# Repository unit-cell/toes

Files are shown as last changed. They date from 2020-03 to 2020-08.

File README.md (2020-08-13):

# toes
A device that sends USB and DIN MIDI messages using four footswitches, a sustain pedal and an expression pedal as the interface. This project is a very easy DIY build that consists of very few through-hole components, recommended for beginners!

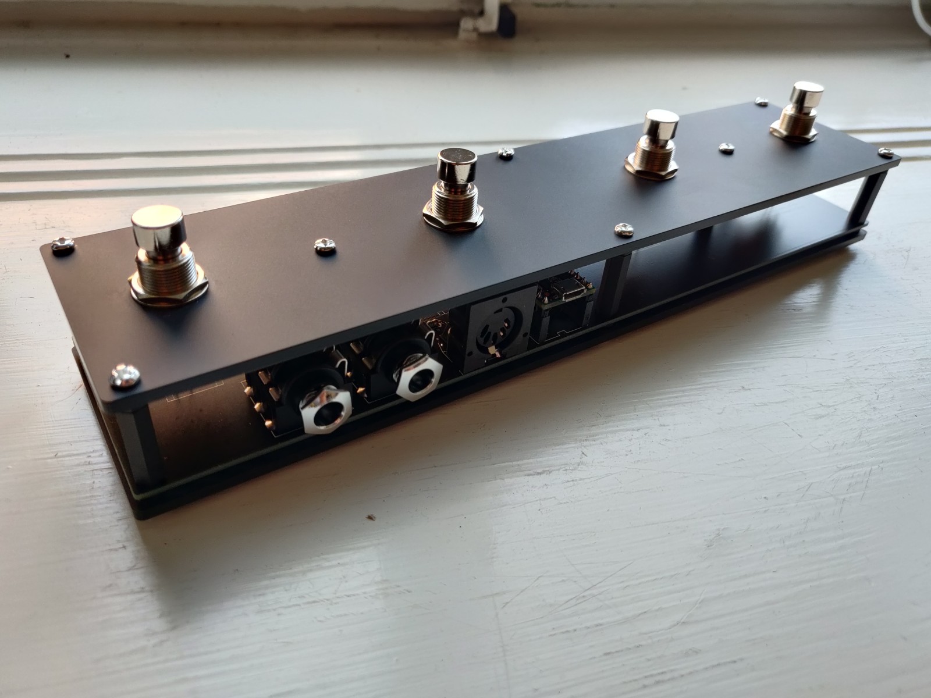
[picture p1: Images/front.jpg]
front


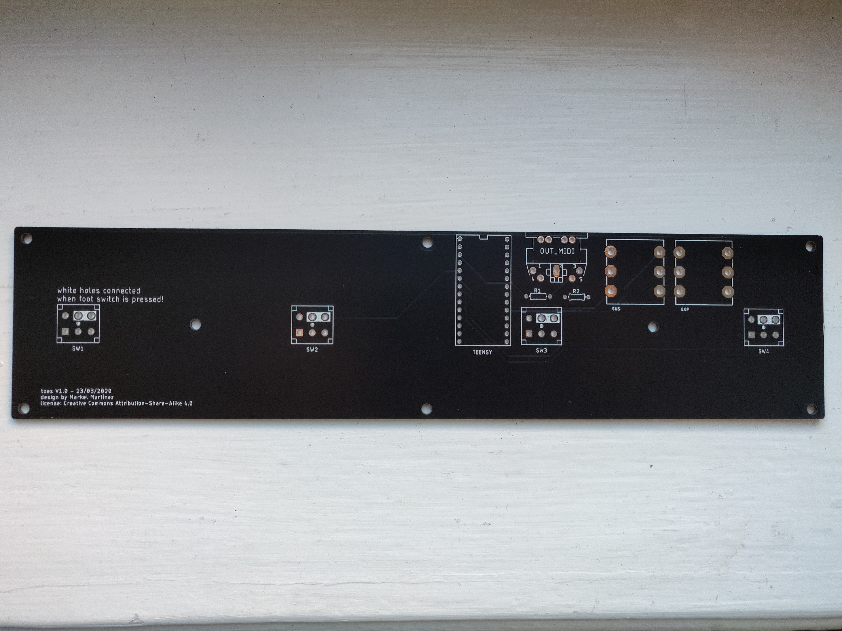
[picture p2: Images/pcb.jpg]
pcb


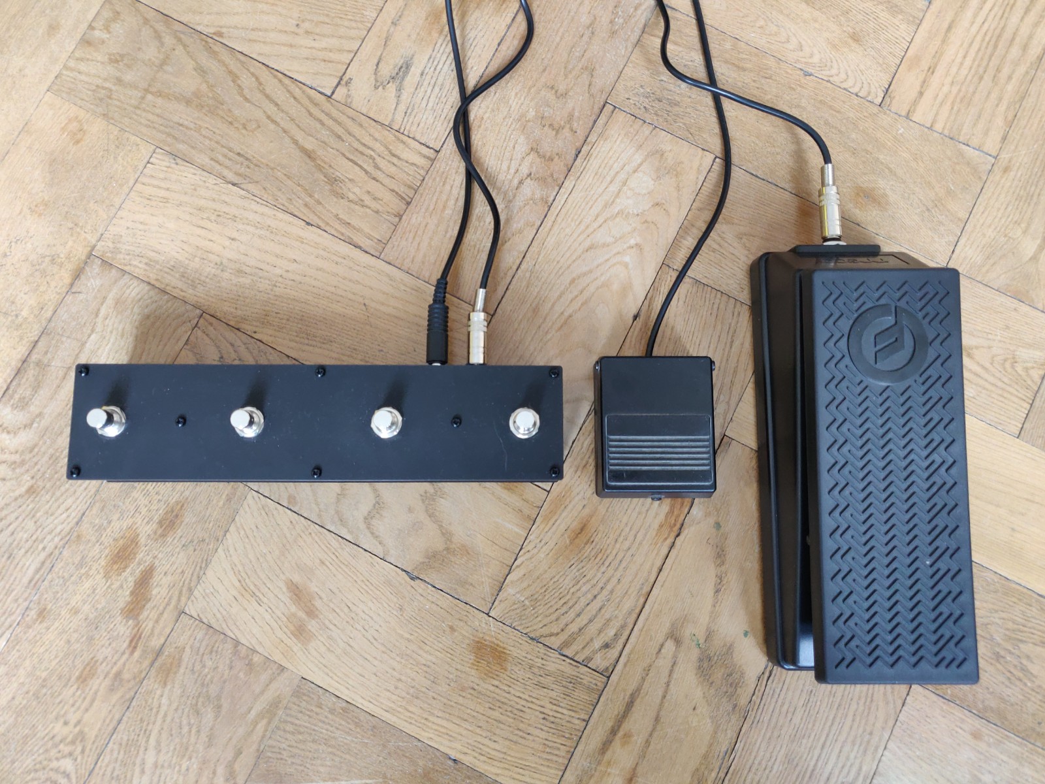
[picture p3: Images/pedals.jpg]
pedals


## Software
Requirements: Bounce2 library, MIDI library (found in Arduino IDE library manager).

To set custom MIDI messages, change settings in config.h file and then compile.

## Foot switches 
They send a note on MIDI message when pressed, and a note off message when released.

## Sustain and expression pedals
The sustain pedal works the same as the foot switches. It is assumed that the sustain pedal will short the tip and sleeve of the jack while it is not pressed, and interrupt the connection when it is pressed. The code could be modified for the opposite situation.

The expression pedal sends a MIDI CC message. This design carries 5V on the tip, the wiper on the ring, and ground on the sleeve of the TRS jack.

## USB and DIN midi
The USB port on the teensy powers the unit and sends USB midi messages, and there is also a DIN MIDI out socket.

## Build guide
First solder R1, R2, the teensy pin sockets, MIDI DIN socket, and the stereo jack sockets for the pedals. All of them go on the top of the board, as shown in the picture below. **Do not solder the foot switches yet, if you are are building toes with a MIDI DIN socket**.*

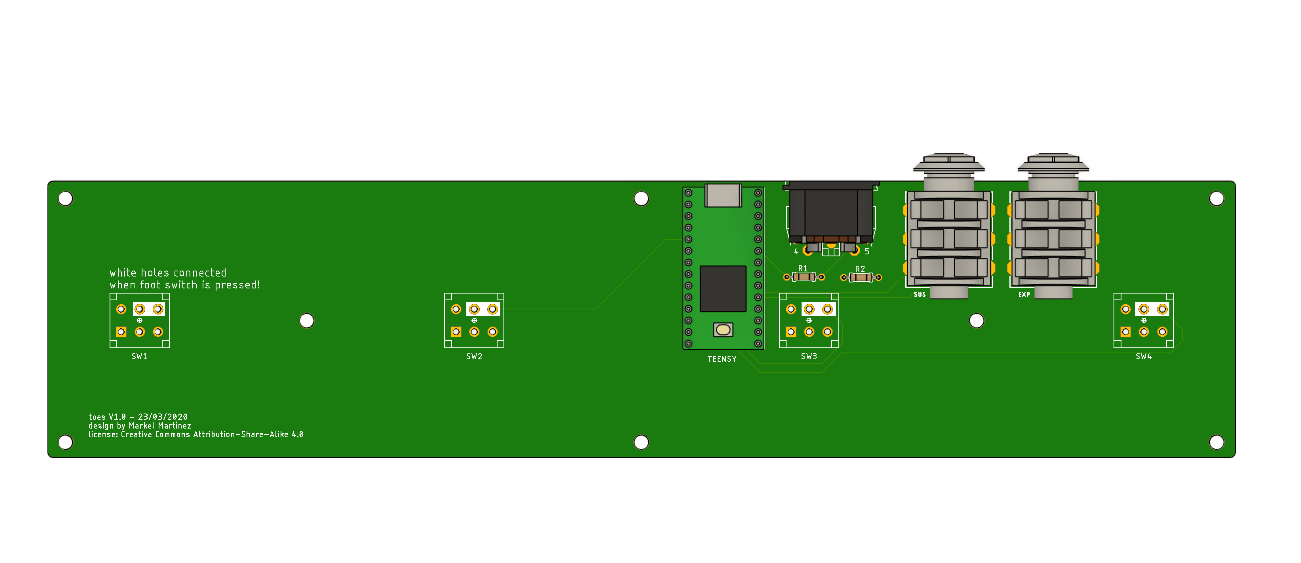
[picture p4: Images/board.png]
toes board


Then screw the foot switches to the top panel. Solder short cables or resistor legs to the foot switch legs that will be connected to the PCB. These are the legs that *become connected when the foot switch is pressed*. Mount the PCB to the top panel with the 22 mm spacers (I used a 20 mm spacer + a nut), and solder the wire/legs to the pads highlighted by the white mark on the silkscreen.

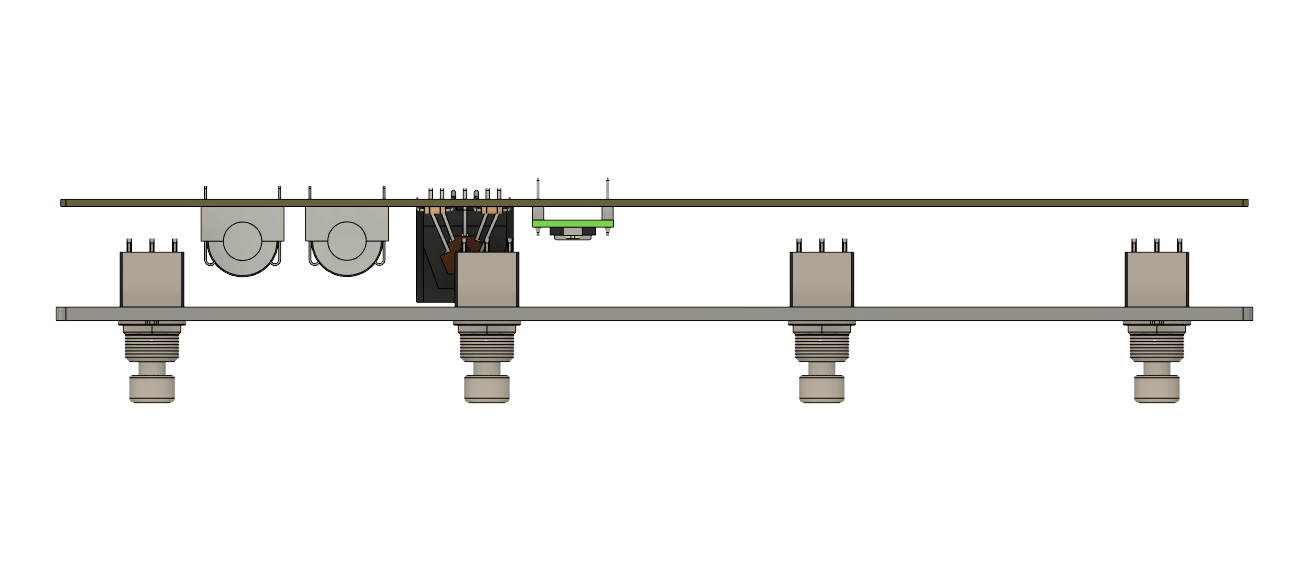
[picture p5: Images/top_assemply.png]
top assembly


You can trim the long legs on the bottom of the board if you are using nuts as spacers for the bottom panel. Assemble these and you are done!

Note about foot switches: it is possible to use any momentary foot switch with enough clearance to fit between the top panel and the board. Just make sure to wire it to the holes marked with a white rectangle, so that these become connected when pressing the switch.

*If you want a lower profile and don't need a MIDI DIN socket, you can get the footswitches listed in the BOM as FS5700SPMT2B2M2QE. These have solder pins instead of solder lugs and can be soldered directly on to the board.

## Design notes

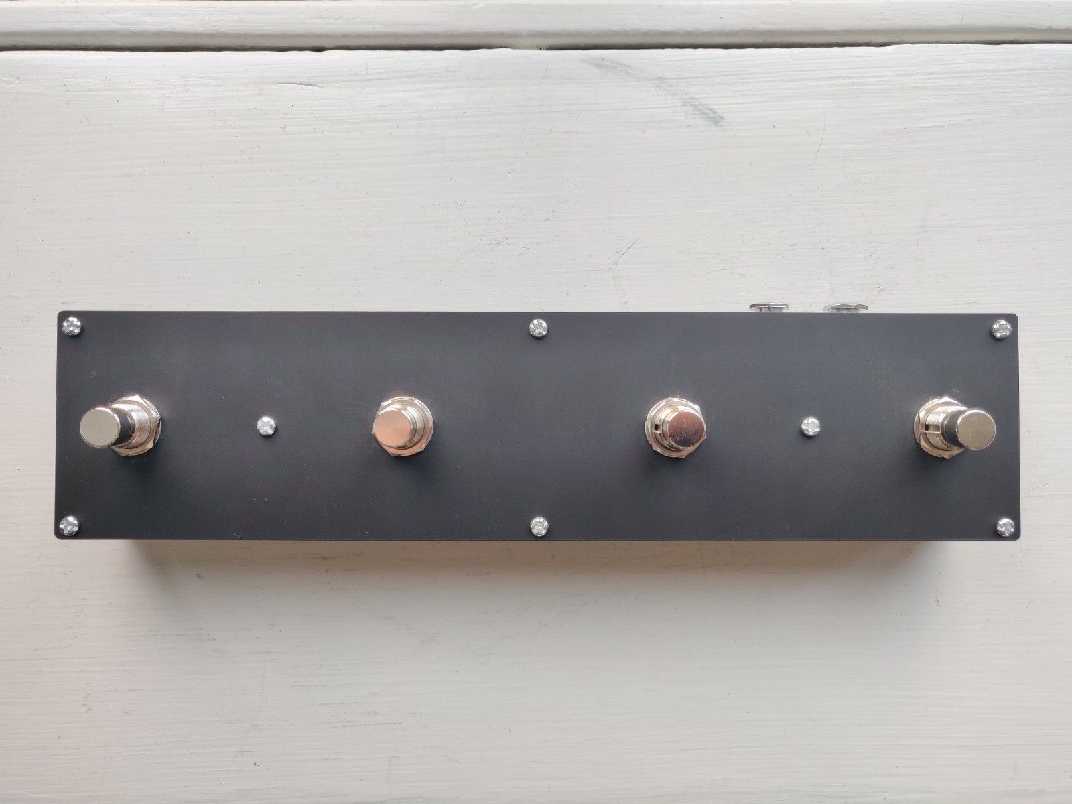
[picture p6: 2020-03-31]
Images/top.jpg

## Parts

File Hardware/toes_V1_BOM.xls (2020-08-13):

Toes BOM
Part | Quantity | Value | Mouser ref | Comments
R1, R2 | 2 | 47 ohm | 660-MFS1/4DCT52R47R0 | -
SW1-4 | 4 | - | 612-FS57SPMT2B2M1QE* | Use FS57SPMT2B2M2QE if you don't need DIN midi and will solder these to the board directly! These have solder pins instead of solder lugs.
MIDI socket | 1 | - | 502-57PC5F | Any 5 pin PCB mounted female socket will do.
SUS, EXP | 2 | - | 550-22302 | Stereo ¼ inch jacks.
Teensy pin sockets | 2 | - | 200-SLW11401TS | 14 position female pin strips.
Teensy 3.2 | 1 | - | 485-2756 | Might be cheaper from other sources.
Hardware
Part | Quantity | Comments
M3 screws long | 8 | Bottom side.
M3 screws short | 8 | Top side.
M3 FF spacers 22 mm | 8 | You can stack 2 spacers to a height of roughly 22 mm.
M3 nuts 2 mm | 8 | These are for the bottom side of the PCB.
Rubber feet | 4 | -
* Make sure that the legs you solder to the holes under the white rectangle mark are connected only when the switch is pressed! Test continuity with a multimeter if you are unsure.

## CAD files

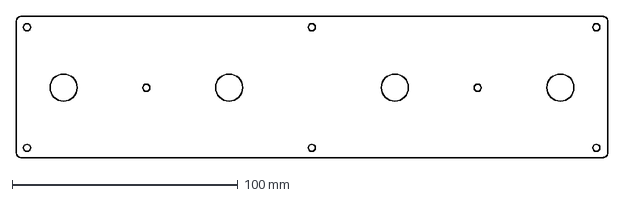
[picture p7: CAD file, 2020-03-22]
Hardware/toes_panel_top.dxf
262.0 x 62.5 mm

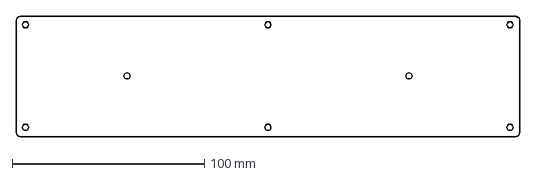
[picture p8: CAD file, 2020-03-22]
Hardware/toes_panel_bottom.dxf
262.0 x 62.5 mm

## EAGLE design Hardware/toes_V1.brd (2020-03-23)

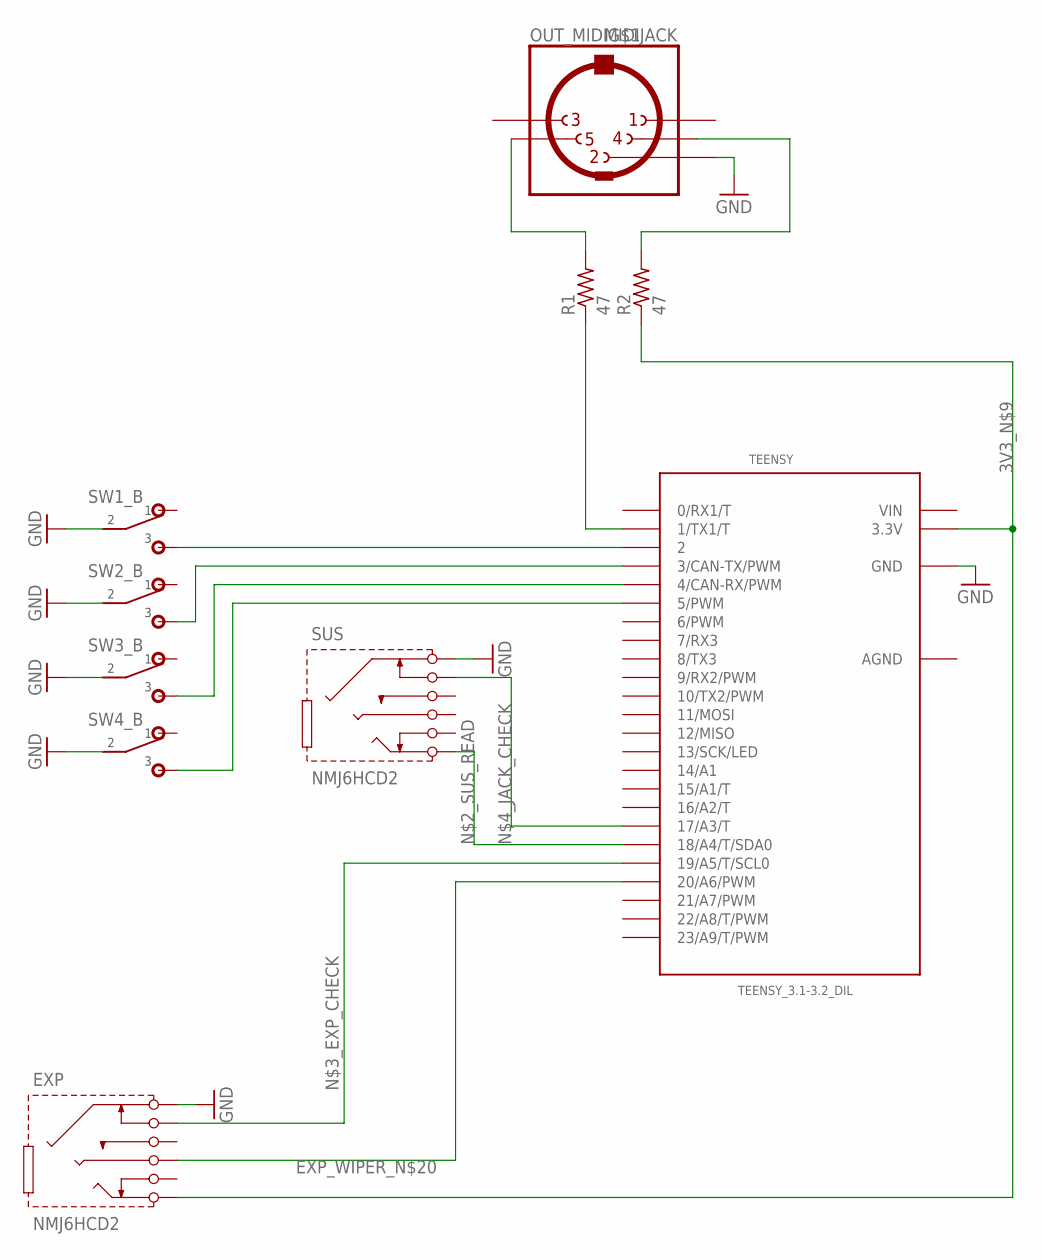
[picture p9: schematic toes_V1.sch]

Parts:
EXP: NMJ6HCD2
OUT_MIDI: MIDIJACK; CP-2350
R1, R2: 47; 0204/7
SUS: NMJ6HCD2
SW1, SW2, SW3, SW4: DPDTDPDT_MOM; SF12011F-0202-20R-M-011
TEENSY: TEENSY_3.1-3.2_DIL; TEENSY_3.0-3.2&LC_DIL

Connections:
3V3_N$9: EXP.T (TIP), R2.1, TEENSY.3.3V
AGND: TEENSY.AGND
EXP_WIPER_N$20: EXP.R (RING), TEENSY.20/A6 (20/A6/PWM)
GND: EXP.S (SLEEVE), OUT_MIDI.2, SUS.S (SLEEVE), SW1.P$5 (2), SW2.P$5 (2), SW3.P$5 (2), SW4.P$5 (2), TEENSY.GND
MIDI_OUT_N$8: R1.1, TEENSY.1 (1/TX1/T)
unnamed: OUT_MIDI.4, R2.2
unnamed: SUS.T (TIP), TEENSY.18/A4 (18/A4/T/SDA0)
unnamed: OUT_MIDI.5, R1.2
unnamed: EXP.SN (SLEEVE-S), TEENSY.19/A5 (19/A5/T/SCL0)
unnamed: SUS.SN (SLEEVE-S), TEENSY.17/A3 (17/A3/T)
SW1_N$14: SW1.P$6 (3), TEENSY.2
SW2_N$15: SW2.P$6 (3), TEENSY.3 (3/CAN-TX/PWM)
SW3_N$16: SW3.P$6 (3), TEENSY.4 (4/CAN-RX/PWM)
SW4_N$17: SW4.P$6 (3), TEENSY.5 (5/PWM)
VIN: TEENSY.VIN

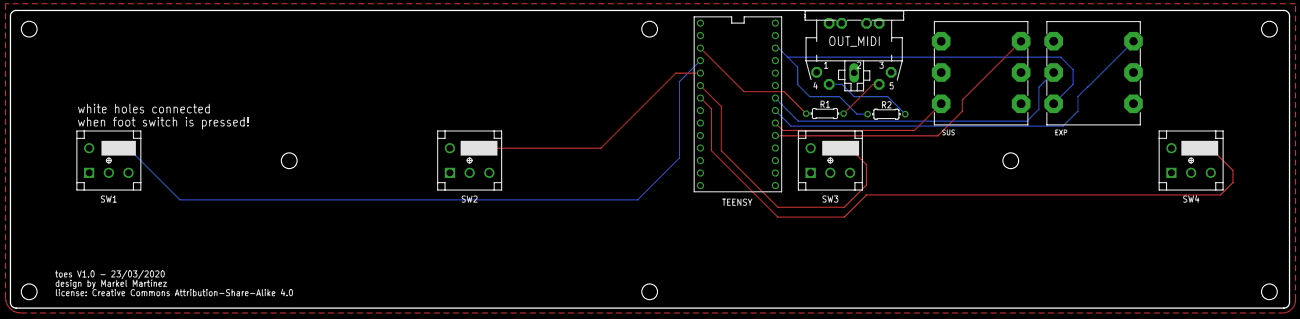
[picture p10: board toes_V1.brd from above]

Board: 2 copper layers, 260.0 x 60.5 mm, 10 parts (0 on the bottom side), 13 nets.

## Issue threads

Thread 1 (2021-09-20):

Where can we find the PCB?

julientaq, 2021-09-20:
Hi there
amazing project!
Do you have any plan to make those pcb available?

Thanks!

unit-cell, 2021-09-21:
Hey Julien, thanks for the kind words! The PCB files are on the github repo
if that's what you meant. I also have some PCBs left from my first order, I
have been sending them out for 80 SEK + shipping if you're interested.

Best,
Markel

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

julientaq, 2021-09-21:
That’s exactly what i had in mind :)

i’ll be happy to get a couple of pcb. i’m in france, so i don’t know how much the shipping would be. (but i’m all up for that)

unit-cell, 2021-09-21:
Great! Just checked and it seems the shipping would be 130 SEK. Let me know
if it sounds reasonable, and if you give me your address I can post them
asap!

Cheers,
Markel

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

julientaq, 2021-09-22:
We’re good!
How can i send you my address and the money?
I don’t really trust github to be the best place for that :)

unit-cell, 2021-09-22:
Right, did't even notice this was a github issue! I was following on my
email. You can email me your address at markelmc92 [at] gmail.com, we can
continue communicating there!

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

Closed 2021-09-22.

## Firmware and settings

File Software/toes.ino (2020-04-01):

#include <Bounce2.h>
#include <MIDI.h>
#include "config.h"

// MIDI 
MIDI_CREATE_INSTANCE(HardwareSerial, Serial1, MIDI);

// expression pedal
byte jack_check_exp = LOW;      // HIGH when exp. pedal present
byte jack_check_sustain = LOW;  // HIGH when sus pedal present
int expression = 0;             // exp. pedal reading on pin 20 (A6)
int expression_last = 0;        // exp. pedal reading from previous loop
int expression_threshold = 10;  // threshold for detection of movement
int cc_mapped = 0;              // reading mapped to 0-127              

// debouncing
Bounce sw1 = Bounce(2, 5); // debounce pin 2, 5ms debounce time
Bounce sw2 = Bounce(3, 5); // debounce pin 3, 5ms debounce time
Bounce sw3 = Bounce(4, 5); // debounce pin 4, 5ms debounce time
Bounce sw4 = Bounce(5, 5); // debounce pin 5, 5ms debounce time

Bounce sus_pedal = Bounce(18, 10); // debounce pin 18, 10 ms debounce time
Bounce jack_check_sus = Bounce(17, 5); // debounce pin 17, 5 ms debounce time

void setup() {
  MIDI.begin();
  // switches
  pinMode(2, INPUT_PULLUP);  // SW1
  pinMode(3, INPUT_PULLUP);  // SW2
  pinMode(4, INPUT_PULLUP);  // SW3
  pinMode(5, INPUT_PULLUP);  // SW4
   
  // expression pedal
  pinMode(19, INPUT_PULLUP); // jack_check_exp, LOW when no jack
  pinMode(A6, INPUT); // read voltage on wiper pin

  // sustain pedal
  pinMode(17, INPUT_PULLUP); // jack_check_sus, LOW when no jack
  pinMode(18, INPUT_PULLUP); // LOW when pressed
}

void loop() {
  // switch reading
  sw1.update();
  sw2.update();
  sw3.update();
  sw4.update();

  // switch MIDI messages
  if (sw1.fallingEdge()) {
    usbMIDI.sendNoteOn(note1, 99, midi_out_channel);  
    MIDI.sendNoteOn(note1, 99, midi_out_channel);
  }
  if (sw1.risingEdge()) {
    usbMIDI.sendNoteOff(note1, 0, midi_out_channel);
    MIDI.sendNoteOff(note1, 0, midi_out_channel); 
  }
  if (sw2.fallingEdge()) {
    usbMIDI.sendNoteOn(note2, 99, midi_out_channel);  
    MIDI.sendNoteOn(note2, 99, midi_out_channel);
  }
  if (sw2.risingEdge()) {
    usbMIDI.sendNoteOff(note2, 0, midi_out_channel);
    MIDI.sendNoteOff(note2, 0, midi_out_channel); 
  }
  if (sw3.fallingEdge()) {
    usbMIDI.sendNoteOn(note3, 99, midi_out_channel);  
    MIDI.sendNoteOn(note3, 99, midi_out_channel);
  }
  if (sw3.risingEdge()) {
    usbMIDI.sendNoteOff(note3, 0, midi_out_channel);
    MIDI.sendNoteOff(note3, 0, midi_out_channel); 
  }
  if (sw4.fallingEdge()) {
    usbMIDI.sendNoteOn(note4, 99, midi_out_channel);  
    MIDI.sendNoteOn(note4, 99, midi_out_channel);
  }
  if (sw4.risingEdge()) {
    usbMIDI.sendNoteOff(note4, 0, midi_out_channel);
    MIDI.sendNoteOff(note4, 0, midi_out_channel); 
  }

  // SUSTAIN PEDAL: if pin 17 NOT LOW, check if pin 18 is LOW and if so send note.
  jack_check_sus.update();
  sus_pedal.update();
  jack_check_sustain = digitalRead(17);

  // first IF is for sending note_off when unplugging jack.
  if (jack_check_sus.fallingEdge()){
    usbMIDI.sendNoteOff(note_sus, 0, midi_out_channel);
    MIDI.sendNoteOff(note_sus, 0, midi_out_channel);     
  }
  // these IF statements might have to be reversed for a different pedal
  if (jack_check_sustain == HIGH) {
    if (sus_pedal.risingEdge()) {
      usbMIDI.sendNoteOn(note_sus, 99, midi_out_channel);  
      MIDI.sendNoteOn(note_sus, 99, midi_out_channel);
    }
    if (sus_pedal.fallingEdge()) {
      usbMIDI.sendNoteOff(note_sus, 0, midi_out_channel);
      MIDI.sendNoteOff(note_sus, 0, midi_out_channel); 
    }    
  }  
  
  // EXPRESSION PEDAL: if pin 19 NOT LOW, read pin 20 and map to midi CC
  jack_check_exp = digitalRead(19);
  if (jack_check_exp == HIGH) {
    expression = analogRead(A6);
    if (abs(expression - expression_last) > expression_threshold) {
      expression_last = expression;
      cc_mapped = map(expression, 0, 1023, 0, 128); // chose 128 upper bound because sometimes the max value will not be read
      if (cc_mapped == 128) {                       // correct for 0-127
        cc_mapped = 127;
      }
      usbMIDI.sendControlChange(midi_cc, cc_mapped, midi_out_channel);
      MIDI.sendControlChange(midi_cc, cc_mapped, midi_out_channel);
    }
  }
  while (usbMIDI.read()) {
  // ignore incoming messages
  }
}

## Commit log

2020-04-01 fixed MIDI DIN out
    [toes.ino]
2020-04-01 added .xls BOM
    [toes_V1_BOM.xls]
2020-04-01 added BOM in csv format
    [toes_V1_BOM.csv]

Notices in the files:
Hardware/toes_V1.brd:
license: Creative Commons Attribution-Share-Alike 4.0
